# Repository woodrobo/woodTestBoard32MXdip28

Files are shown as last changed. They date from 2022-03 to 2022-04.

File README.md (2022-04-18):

# woodTestBoard32MXdip28

PIC32MX2xxのDIP28ピンマイコンの評価ボードです。「お手軽DIPマイコンのPIC32MXを始めよう(仮称)」に対応しています。

BOOTH(https://woodrobo.booth.pm/items/3751749)で販売しています。

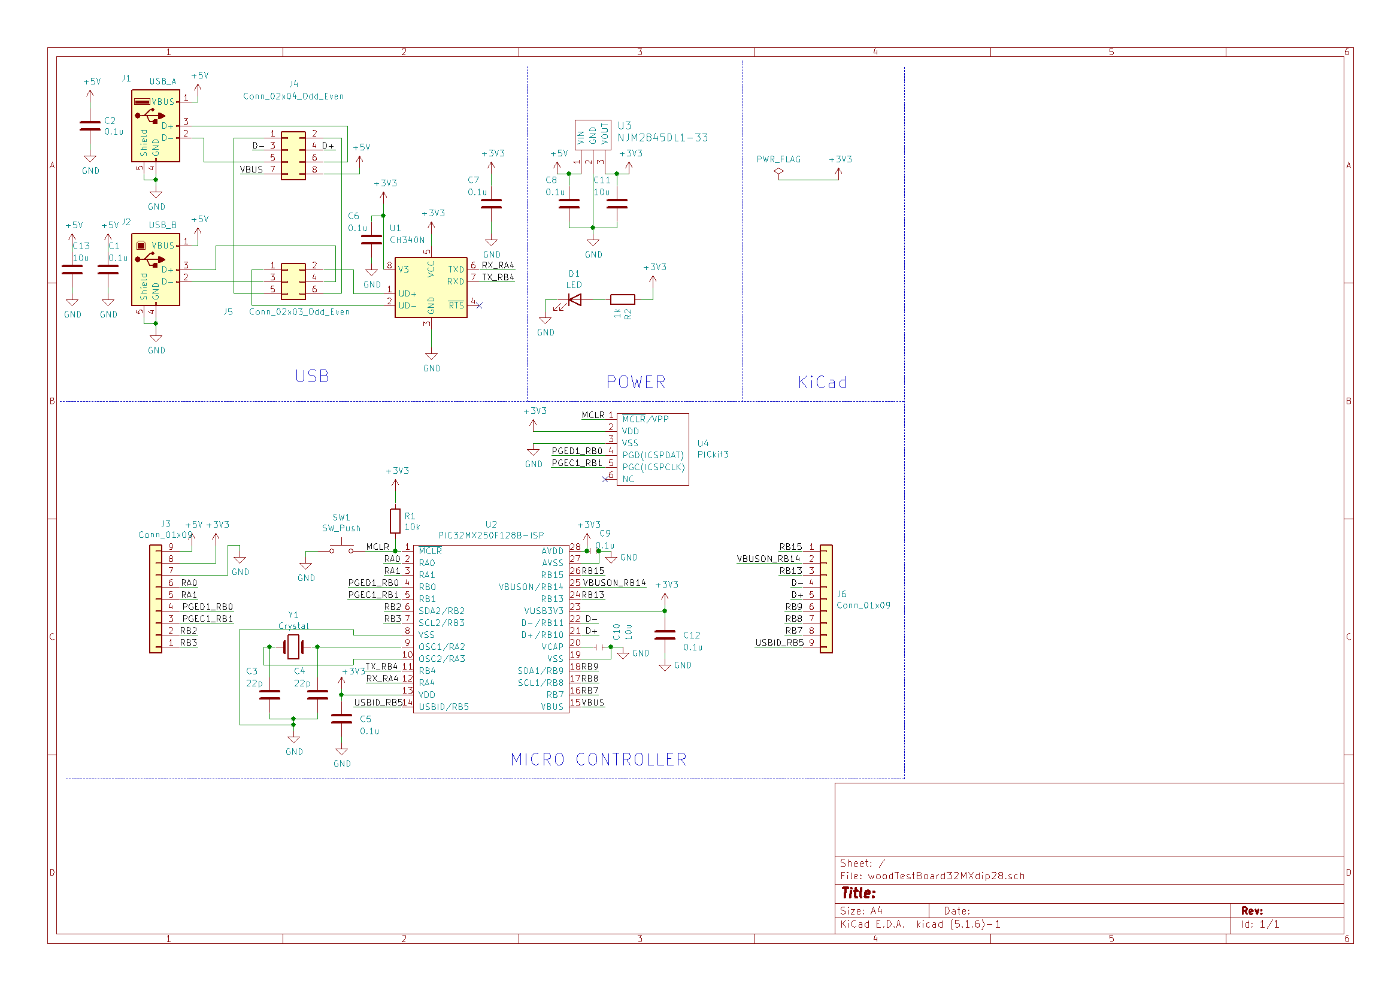
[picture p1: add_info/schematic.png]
回路図
  

実物(表)
実物(裏)  

## USBピンヘッダについて  
USBコネクタの近くに2つピンヘッダがついていると思います。これはUSB関連の接続をするためものです。単純な回路ですので詳細は回路図をご覧ください。  
  
USB B SELECT  
USB Bコネクタ(パソコンと接続する時のコネクタ)のUSB通信線(D+,D-)の配線をすることができます。B-CH340で接続すればUSBシリアル変換ICを利用することができます。(ArduinoでいうSerial.printでパソコンに文字を表示できるようになる)B-PICで接続すれば下にあるPIC MCU USB TESTのDEVICE(B)に配線をつなげることができます。  
  
PIC MCU USB TEST  
PICマイコンのUSB関連の配線をすることができます。PIC-DEVICE(B)で接続＆USB B SELECTでB-PICで接続すればPICをUSB Bコネクタに繋げられUSB DEVICE機能を試すことができます。PIC-HOST(A)で接続すればUSB Aコネクタに繋げられUSB HOST機能を試すことができます。  
VBUS-5VはUSBモジュール使用の時に必要になることがあるので繋げておいてください。	  
  
# 書き込みについて  
ボード右側にあるICSP用ピンヘッダは 写真のように三角マークがあるピンがMCLRです。書き込み器には同じように三角マークがあるので三角マーク同士を合わせるように接続してください。例えばPickit3では写真のように書き込み器の裏面が見えるような向きになると思います。  
  
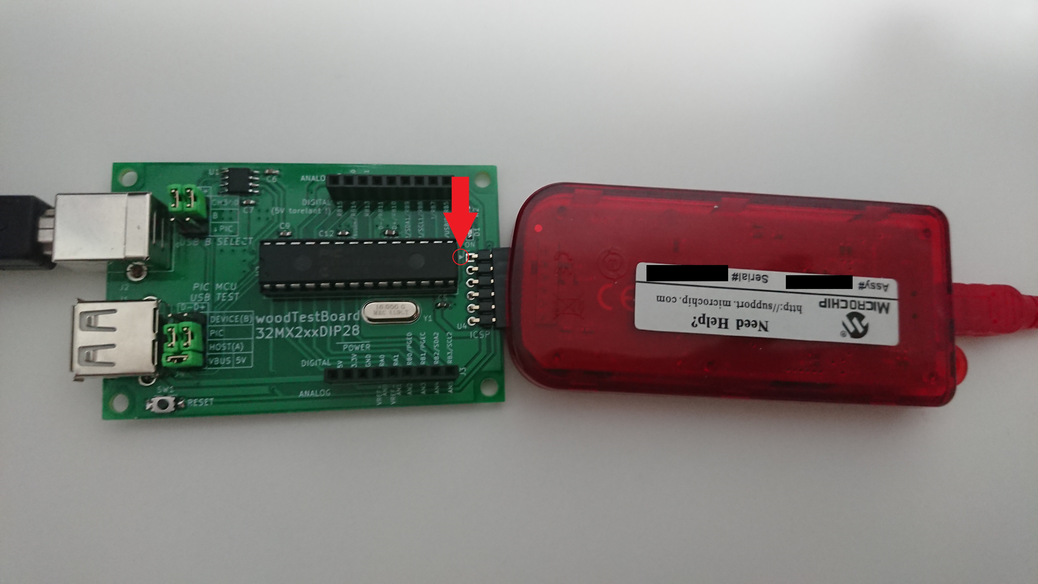
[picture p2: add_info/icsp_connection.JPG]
ICSPの接続
  

# 部品について

(はんだづけする際に見る)部品表や(部品を購入する際に見る)部品個数表はadd_infoフォルダを見てください。  
価格は1部品あたりの値段を計算していますので複数個入りで販売されている部品に関しては購入金額はこれよりも高くなります。  
チップ部品セットとがBoothで販売しているチップコンデンサ、抵抗、LEDがセットになったものです。

# はんだづけ

向きを間違えやすい箇所を説明します。

U1のCH340は上下2つある白線のうち伸びている箇所(左上)がピン1です。そのため写真のような向きではんだづけしてください。

CH340のはんだづけ  
  
D1のチップLEDは写真のような向きです。チップLEDの裏面のほうが分かりやすいため裏面にしたLEDも横に並べています。

CH340のはんだづけ

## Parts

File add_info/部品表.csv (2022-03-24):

Reference | Value | Footprint | 説明
C1 | 0.1u | Capacitor_SMD:C_0603_1608Metric_Pad1.05x0.95mm_HandSolder | チップコンデンサ0.1uF
C2 | 0.1u | Capacitor_SMD:C_0603_1608Metric_Pad1.05x0.95mm_HandSolder | チップコンデンサ0.1uF
C3 | 22p | Capacitor_SMD:C_0603_1608Metric_Pad1.05x0.95mm_HandSolder | チップコンデンサ22pF
C4 | 22p | Capacitor_SMD:C_0603_1608Metric_Pad1.05x0.95mm_HandSolder | チップコンデンサ22pF
C5 | 0.1u | Capacitor_SMD:C_0603_1608Metric_Pad1.05x0.95mm_HandSolder | チップコンデンサ0.1uF
C6 | 0.1u | Capacitor_SMD:C_0603_1608Metric_Pad1.05x0.95mm_HandSolder | チップコンデンサ0.1uF
C7 | 0.1u | Capacitor_SMD:C_0603_1608Metric_Pad1.05x0.95mm_HandSolder | チップコンデンサ0.1uF
C8 | 0.1u | Capacitor_SMD:C_0603_1608Metric_Pad1.05x0.95mm_HandSolder | チップコンデンサ0.1uF
C9 | 0.1u | Capacitor_SMD:C_0603_1608Metric_Pad1.05x0.95mm_HandSolder | チップコンデンサ0.1uF
C10 | 10u | Capacitor_SMD:C_0603_1608Metric_Pad1.05x0.95mm_HandSolder | チップコンデンサ10uF
C11 | 10u | Capacitor_SMD:C_0603_1608Metric_Pad1.05x0.95mm_HandSolder | チップコンデンサ10uF
C12 | 0.1u | Capacitor_SMD:C_0603_1608Metric_Pad1.05x0.95mm_HandSolder | チップコンデンサ0.1uF
C13 | 10u | Capacitor_SMD:C_0603_1608Metric_Pad1.05x0.95mm_HandSolder | チップコンデンサ10uF
D1 | LED | LED_SMD:LED_0603_1608Metric_Pad1.05x0.95mm_HandSolder | チップLED赤色
J1 | USB_A | Connector_USB:USB_A_Stewart_SS-52100-001_Horizontal | USB Aコネクタ
J2 | USB_B | Connector_USB:USB_B_OST_USB-B1HSxx_Horizontal | USB Bコネクタ
J3 | Conn_01x09 | Connector_PinSocket_2.54mm:PinSocket_1x09_P2.54mm_Vertical | ピンソケット1×9
J4 | Conn_02x04_Odd_Even | Connector_PinHeader_2.54mm:PinHeader_2x04_P2.54mm_Vertical | ピンヘッダ2×4
J5 | Conn_02x03_Odd_Even | Connector_PinHeader_2.54mm:PinHeader_2x03_P2.54mm_Vertical | ピンヘッダ2×3
J6 | Conn_01x09 | Connector_PinSocket_2.54mm:PinSocket_1x09_P2.54mm_Vertical | ピンソケット1×9
R1 | 10k | Resistor_SMD:R_0603_1608Metric_Pad1.05x0.95mm_HandSolder | チップ抵抗10kΩ
R2 | 1k | Resistor_SMD:R_0603_1608Metric_Pad1.05x0.95mm_HandSolder | チップ抵抗1kΩ
SW1 | SW_Push | 0_kicad_wood:SW_TVAF06-A020B-R | 表面実装スイッチ
U1 | CH340N | Package_SO:SOIC-8_3.9x4.9mm_P1.27mm | USBシリアル変換IC CH340
U2 | PIC32MX250F128B-ISP | Package_DIP:DIP-28_W7.62mm_Socket | ICソケット28ピン
U3 | NJM2845DL1-33 | Package_TO_SOT_SMD:TO-252-2 | 3.3V3端子レギュレータ NJM2845DL1-33
U4 | PICkit3 | Connector_PinHeader_2.54mm:PinHeader_1x06_P2.54mm_Horizontal | L字ピンヘッダ1×6
Y1 | Crystal | Crystal:Crystal_HC49-U_Vertical | 水晶振動子16MHz

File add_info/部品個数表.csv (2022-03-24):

部品名 | 価格 | 個数 | 合計 | サイト | チップ部品セット | 備考
チップコンデンサ0.1uF | 2.5 | 8 | 20 | https://akizukidenshi.com/catalog/g/gP-13374/ | 〇
チップコンデンサ10uF | 15 | 3 | 45 | https://akizukidenshi.com/catalog/g/gP-13161/ | 〇
チップコンデンサ22pF | 2.5 | 2 | 5 | https://akizukidenshi.com/catalog/g/gP-13313/ | 〇
チップLED赤色 | 10 | 1 | 10 | https://akizukidenshi.com/catalog/g/gI-03978/ | 〇
USB Aコネクタ | 50 | 1 | 50 | https://akizukidenshi.com/catalog/g/gC-11551/
USB Bコネクタ | 40 | 1 | 40 | https://akizukidenshi.com/catalog/g/gC-07675/
ピンソケット1×9 | 35 | 2 | 70 | https://akizukidenshi.com/catalog/g/gC-10100/
ピンヘッダ2×7(3+4で割ってください) | 20 | 1 | 20 | https://akizukidenshi.com/catalog/g/gC-00166/ |  | 多めに買うのがオススメ(https://akizukidenshi.com/catalog/g/gC-00082/)
チップ抵抗1kΩ | 0.2 | 1 | 0.2 | https://akizukidenshi.com/catalog/g/gR-14122/ | 〇 | 代替品(https://akizukidenshi.com/catalog/g/gR-11790/)
チップ抵抗10kΩ | 0.2 | 1 | 0.2 | https://akizukidenshi.com/catalog/g/gR-15029/ | 〇 | 代替品(https://akizukidenshi.com/catalog/g/gR-11791/)
表面実装スイッチ | 22 | 1 | 22 | https://akizukidenshi.com/catalog/g/gP-14888/
USBシリアル変換IC CH340 | 60 | 1 | 60 | https://akizukidenshi.com/catalog/g/gI-16305/
PIC32MX250F128B-I/SP | 350 | 1 | 350 | https://akizukidenshi.com/catalog/g/gI-07644/ |  | はんだづけしない
ICソケット28ピン | 20 | 1 | 20 | https://akizukidenshi.com/catalog/g/gP-00013/ |  | 代替品(https://akizukidenshi.com/catalog/g/gP-01339/)
3.3V3端子レギュレータ NJM2845DL1-33 | 50 | 1 | 50 | https://akizukidenshi.com/catalog/g/gI-11299/
L字ピンヘッダ1×6 | 10 | 1 | 10 | https://akizukidenshi.com/catalog/g/gC-05336/
水晶振動子16MHz | 30 | 1 | 30 | https://akizukidenshi.com/catalog/g/gP-08671/
 |  | 合計 | 802.4
ジャンパピン | 4 | 5 | 20 | https://akizukidenshi.com/catalog/g/gP-03687/ |  | USB用ピンヘッダの設定にあると便利

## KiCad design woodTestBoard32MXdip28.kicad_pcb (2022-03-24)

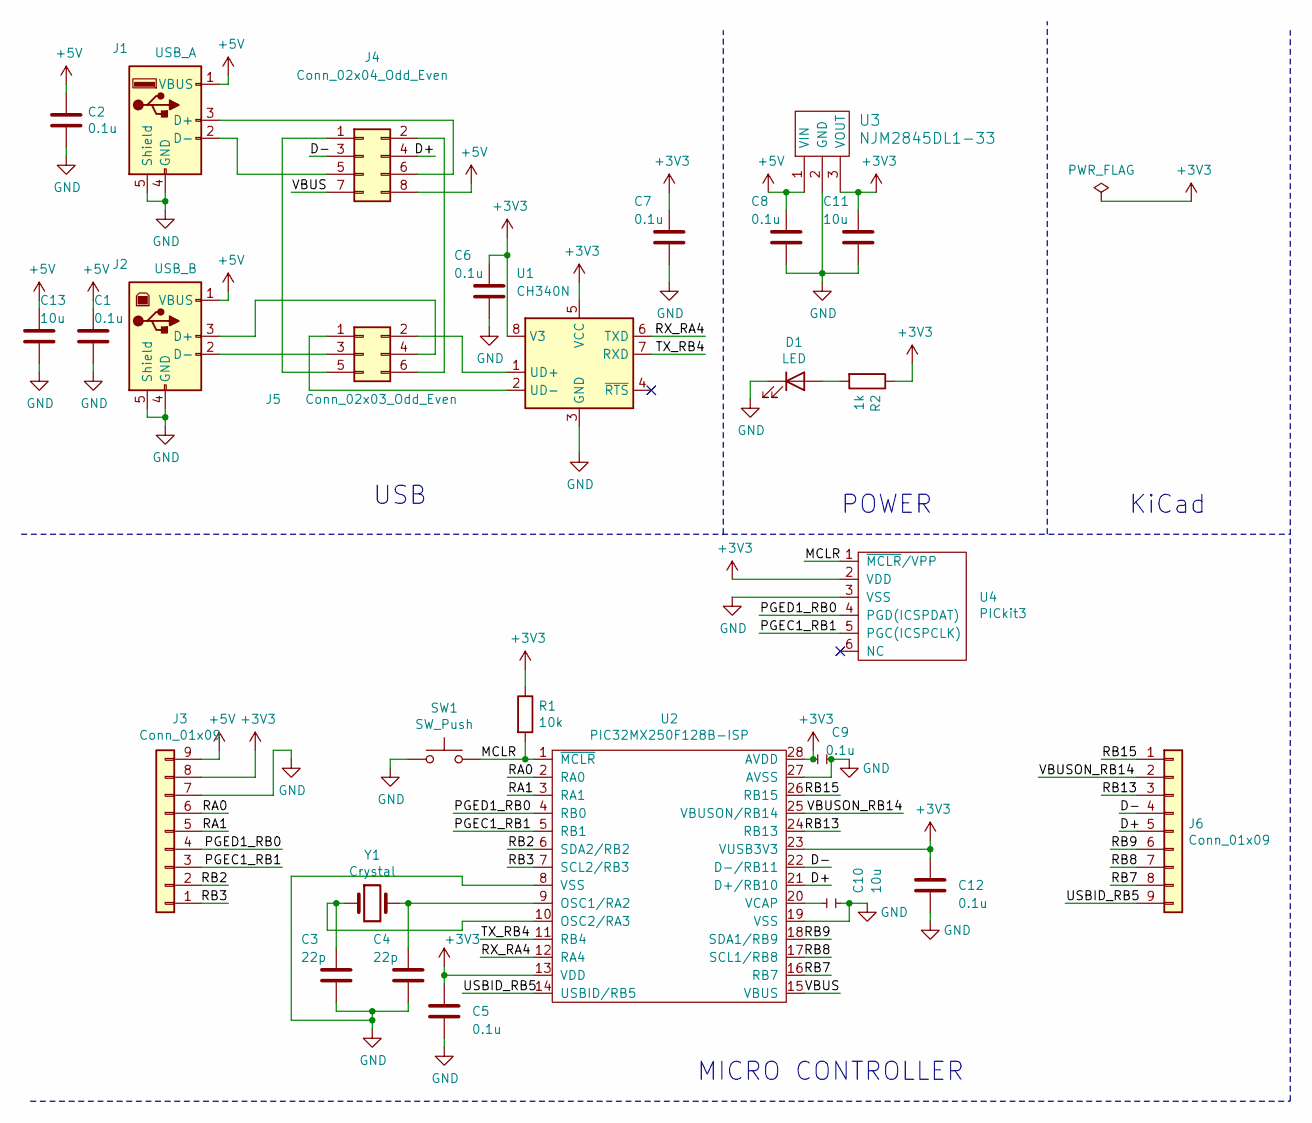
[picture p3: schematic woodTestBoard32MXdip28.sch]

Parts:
C1, C2, C5, C6, C7, C8, C9, C12: 0.1u; C_0603_1608Metric_Pad1.05x0.95mm_HandSolder
C3, C4: 22p; C_0603_1608Metric_Pad1.05x0.95mm_HandSolder
C10, C11, C13: 10u; C_0603_1608Metric_Pad1.05x0.95mm_HandSolder
D1: LED; LED_0603_1608Metric_Pad1.05x0.95mm_HandSolder
J1: USB_A; USB_A_Stewart_SS-52100-001_Horizontal
J2: USB_B; USB_B_OST_USB-B1HSxx_Horizontal
J3, J6: Conn_01x09; PinSocket_1x09_P2.54mm_Vertical
J4: Conn_02x04_Odd_Even; PinHeader_2x04_P2.54mm_Vertical
J5: Conn_02x03_Odd_Even; PinHeader_2x03_P2.54mm_Vertical
R1: 10k; R_0603_1608Metric_Pad1.05x0.95mm_HandSolder
R2: 1k; R_0603_1608Metric_Pad1.05x0.95mm_HandSolder
SW1: SW_Push; SW_TVAF06-A020B-R
U1: CH340N; SOIC-8_3.9x4.9mm_P1.27mm
U2: PIC32MX250F128B-ISP; DIP-28_W7.62mm_Socket
U3: NJM2845DL1-33; TO-252-2
U4: PICkit3; PinHeader_1x06_P2.54mm_Horizontal
Y1: Crystal; Crystal_HC49-U_Vertical

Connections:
+3V3: C5.1, C6.1, C7.1, C9.1, C11.1, C12.1, J3.8, R1.1, R2.1, U1.5 (VCC), U1.8 (V3), U2.13 (VDD), U2.23 (VUSB3V3), U2.28 (AVDD), U3.3 (VOUT), U4.2 (VDD)
+5V: C1.1, C2.1, C8.1, C13.1, J1.1 (VBUS), J2.1 (VBUS), J3.9, J4.8, U3.1 (VIN)
/D+: J4.4, J6.5, U2.21 (D+/RB10)
/D-: J4.3, J6.4, U2.22 (D-/RB11)
/MCLR: R1.2, SW1.2, U2.1 (~MCLR), U4.1 (~MCLR~/VPP)
/PGEC1_RB1: J3.3, U2.5 (RB1), U4.5 (PGC(ICSPCLK))
/PGED1_RB0: J3.4, U2.4 (RB0), U4.4 (PGD(ICSPDAT))
/RA0: J3.6, U2.2 (RA0)
/RA1: J3.5, U2.3 (RA1)
/RB2: J3.2, U2.6 (SDA2/RB2)
/RB3: J3.1, U2.7 (SCL2/RB3)
/RB7: J6.8, U2.16 (RB7)
/RB8: J6.7, U2.17 (SCL1/RB8)
/RB9: J6.6, U2.18 (SDA1/RB9)
/RB13: J6.3, U2.24 (RB13)
/RB15: J6.1, U2.26 (RB15)
/RX_RA4: U1.6 (TXD), U2.12 (RA4)
/TX_RB4: U1.7 (RXD), U2.11 (RB4)
/USBID_RB5: J6.9, U2.14 (USBID/RB5)
/VBUS: J4.7, U2.15 (VBUS)
/VBUSON_RB14: J6.2, U2.25 (VBUSON/RB14)
GND: C1.2, C2.2, C3.2, C4.2, C5.2, C6.2, C7.2, C8.2, C9.2, C10.1, C11.2, C12.2, C13.2, D1.1 (K), J1.4 (GND), J1.5 (Shield), J2.4 (GND), J2.5 (Shield), J3.7, SW1.1, U1.3 (GND), U2.8 (VSS), U2.19 (VSS), U2.27 (AVSS), U3.2 (GND), U4.3 (VSS)
unnamed: C3.1, U2.10 (OSC2/RA3), Y1.1
unnamed: C4.1, U2.9 (OSC1/RA2), Y1.2
unnamed: C10.2, U2.20 (VCAP)
unnamed: D1.2 (A), R2.2
unnamed: J1.2 (D-), J4.5
unnamed: J1.3 (D+), J4.6
unnamed: J2.2 (D-), J5.3
unnamed: J2.3 (D+), J5.4
unnamed: J4.1, J5.5
unnamed: J4.2, J5.6
unnamed: J5.1, U1.2 (UD-)
unnamed: J5.2, U1.1 (UD+)

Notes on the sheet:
USB
POWER
MICRO CONTROLLER
KiCad

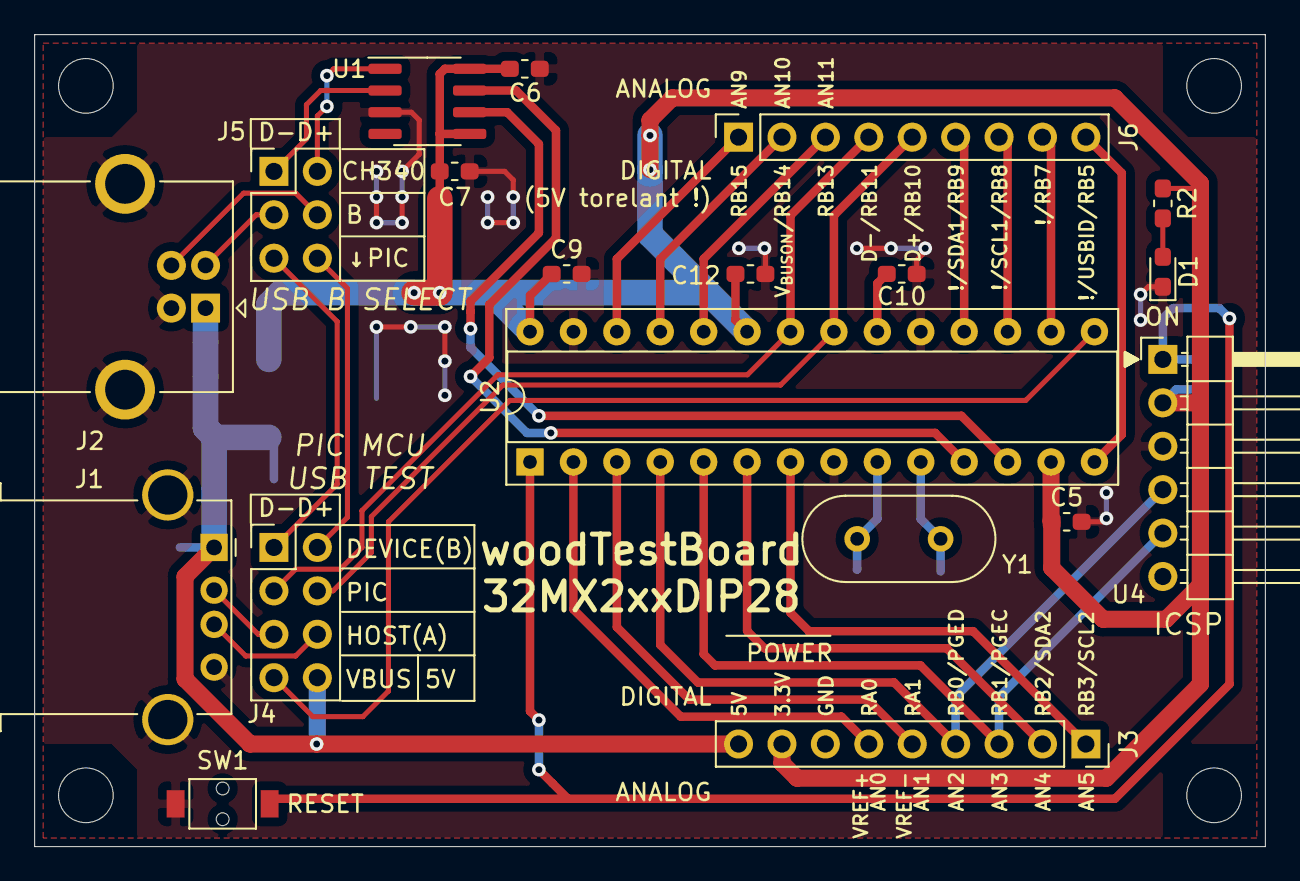
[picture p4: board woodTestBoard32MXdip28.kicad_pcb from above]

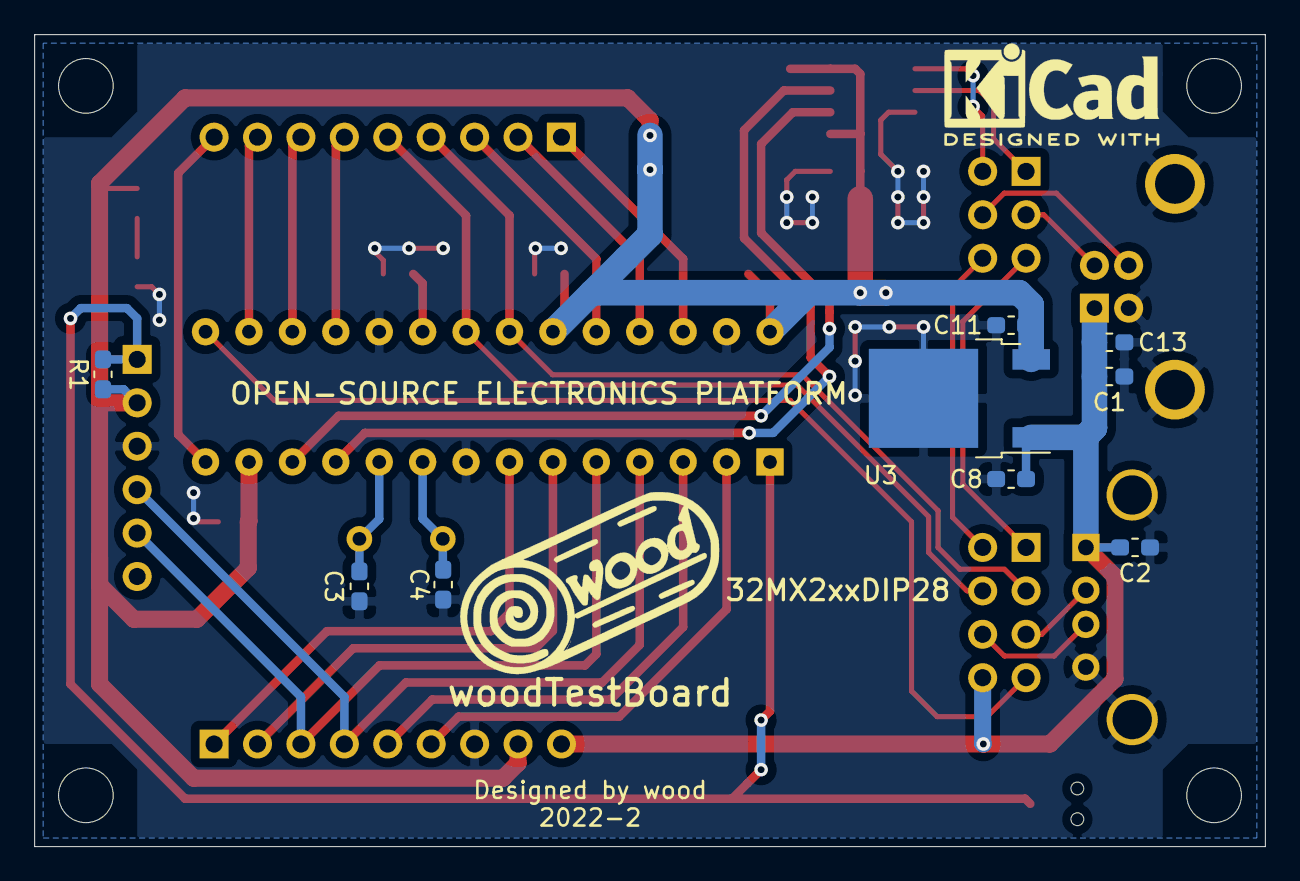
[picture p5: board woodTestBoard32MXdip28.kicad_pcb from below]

Board: 2 copper layers, 72.0 x 47.5 mm, 32 parts (9 on the bottom side), 34 nets.

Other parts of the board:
 : MountingHole_3.2mm_M3
 #2,  #3,  #4: MountingHole_3.2mm_M3

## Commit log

2022-03-24 完成した回路
    [woodTestBoard32MXdip28.kicad_pcb, woodTestBoard32MXdip28.sch]
2022-03-24 説明追加
    [部品個数表.csv, 部品表.csv]
2022-03-24 説明修正
2022-03-26 BOOTH対応
2022-04-03 USBピンヘッダの説明を追加
2022-04-18 ICSP接続の説明を追加
